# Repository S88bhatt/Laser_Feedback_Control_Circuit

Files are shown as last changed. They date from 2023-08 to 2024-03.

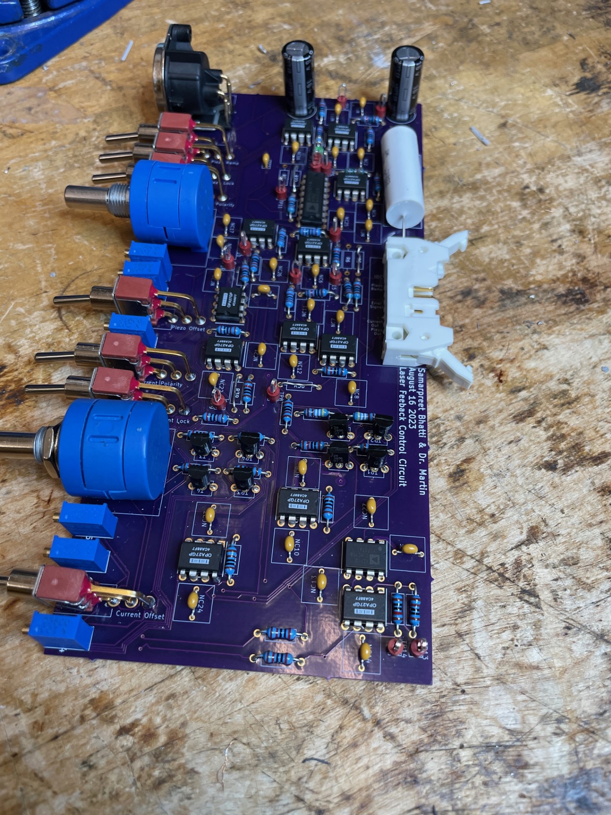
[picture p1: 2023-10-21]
Images/thumbnail_IMG_0441.jpg

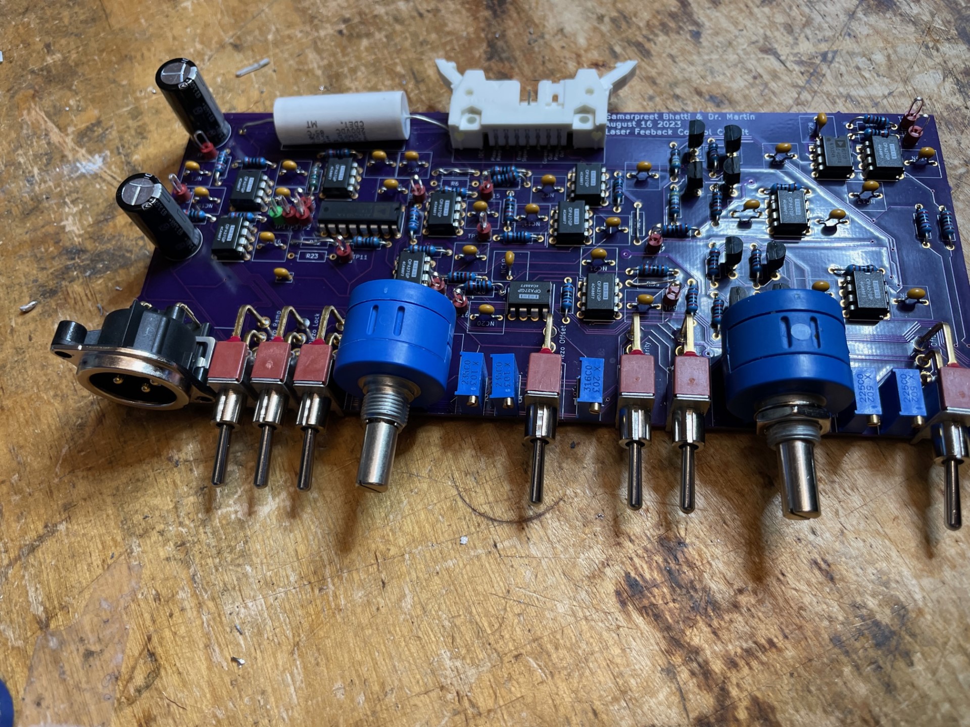
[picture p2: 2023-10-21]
Images/thumbnail_IMG_0439.jpg

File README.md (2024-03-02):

# Laser Feedback Control Circuit
Contains all files in separate folders for the laser feedback control circuit.

## KiCAD
KiCAD Files that are up to date with the most recent and correct version of the circuit, including the PCB layout, schematic, and libraries for footprints and schematic components.

## Gimp
GIMP files which are used for laser cutting the box plating, allowing for a cleaner finish on the final product.

## FreeCAD
FreeCAD files are currently used to cut the box plating into the correct shape.

## Images
Images that show what the physical board looks like once complete.

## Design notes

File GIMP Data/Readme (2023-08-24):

Contains the information to laser cut the lettering onto the box plating

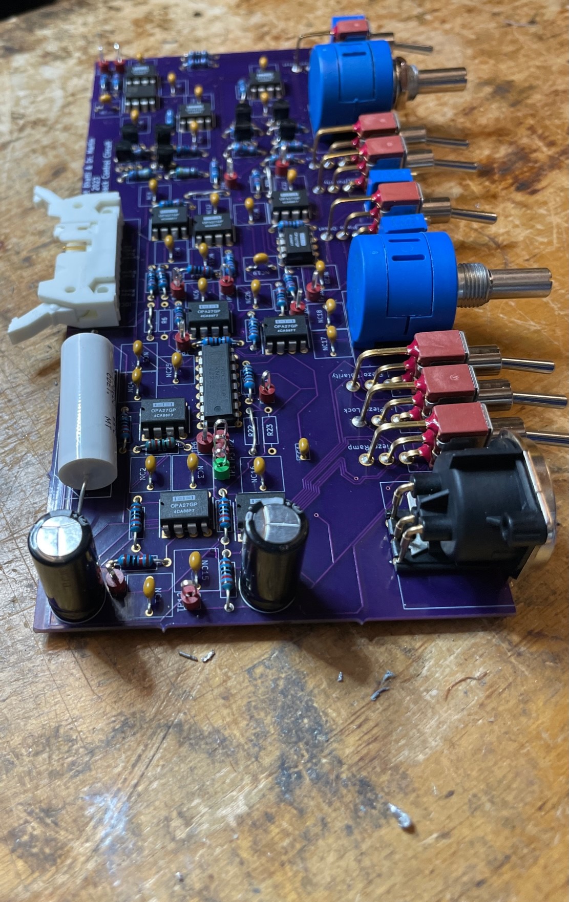
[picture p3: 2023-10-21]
Images/thumbnail_IMG_0442.jpg

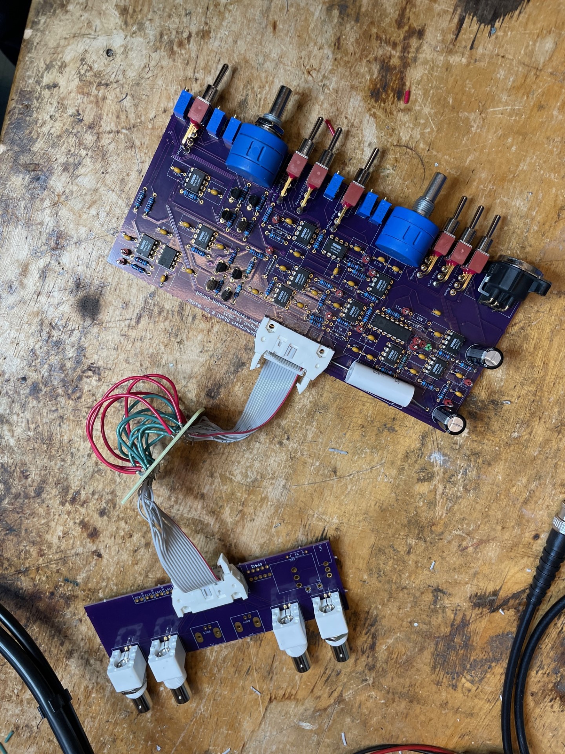
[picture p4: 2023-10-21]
Images/thumbnail_IMG_0443.jpg

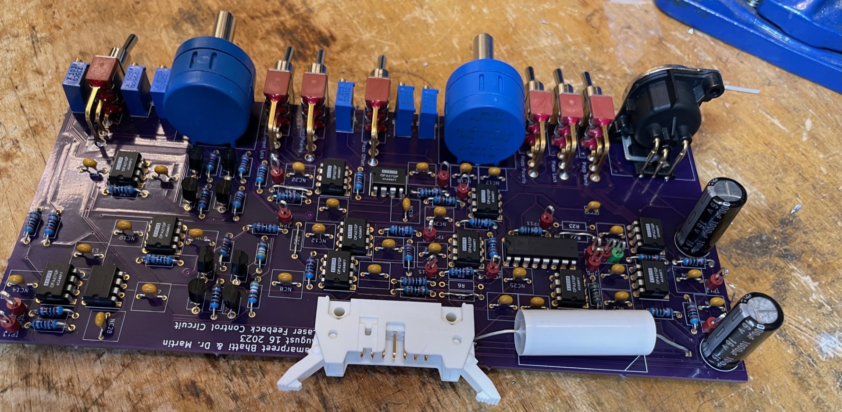
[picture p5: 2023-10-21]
Images/thumbnail_IMG_0440.jpg

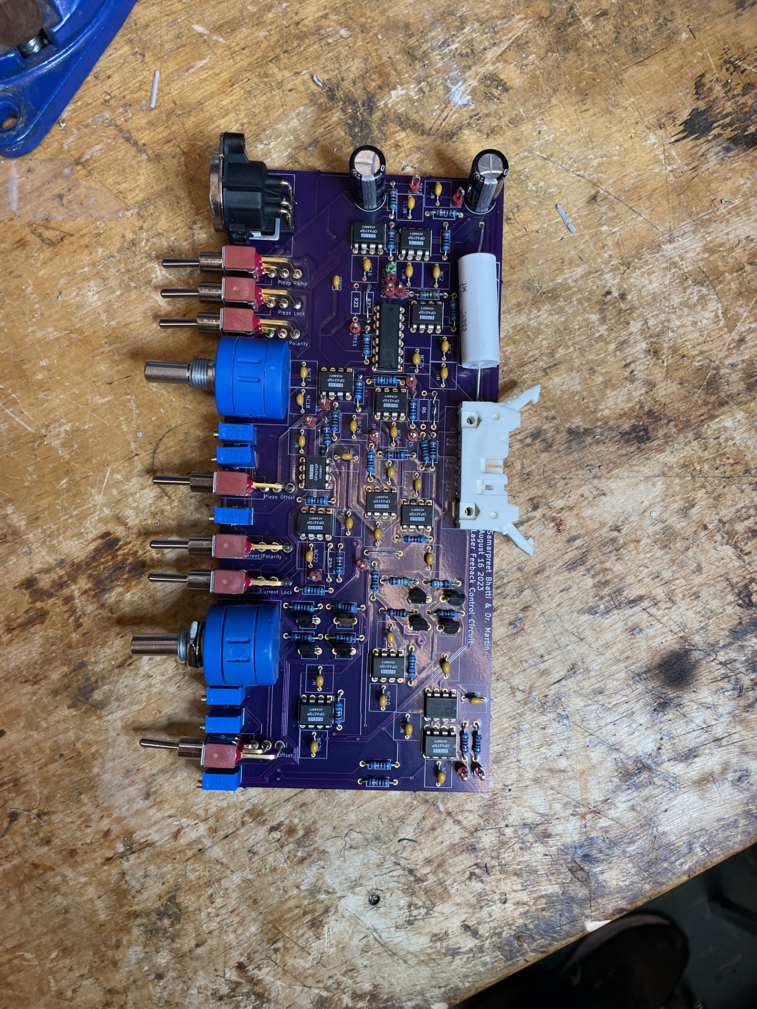
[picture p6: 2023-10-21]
Images/thumbnail_IMG_0438.jpg

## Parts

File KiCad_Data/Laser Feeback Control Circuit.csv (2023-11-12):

Source: | C:\Users\samar\OneDrive\Desktop\SAMARPREET\KiCad\7.0\projects\Laser Feeback Control Circuit\Laser Feeback Control Circuit.kicad_sch
Date: | 2023-10-27 6:58:08 PM
Tool: | Eeschema 7.0.7
Generator: | C:\Program Files\KiCad\7.0\bin\scripting\plugins/bom_csv_grouped_by_value_with_fp.py
Component Count: | 103
Ref | Qnty | Value | Cmp name | Footprint | Description | Vendor | DNP
C1 | 1 | 1uF | Ploypropylene Capacitor | Complex_Op_Amps_Footprints:Polypropylene Capacitor
DG1 | 1 | P/N: ADG201AKNZ | DG201HSDY-T1-E3 | Complex_Op_Amps_Footprints:ADG201AKNZ | Analog Switch ICs HIGH SPEED QUAD SPST A/S
EC1, EC2 | 2 | 1000uF | EEU-EB1C102 | Complex_Op_Amps_Footprints:ELECTROLYTIC CAPACITOR - EEU-EB1C102 | PANASONIC - EEU-EB1C102 - ALUMINUM ELECTROLYTIC CAPACITOR, 1000UF, 20%, 16V, RADIAL
IDC1 | 1 | Male 14 Position IDC Connector, Digikey P/N: 609-5970-ND | 14_Position_Male_IDC | Complex_Op_Amps_Footprints:Male IDC Connector
NC1, NC2, NC6, NC7, NC11, NC14, NC19, NC23, NC25, NC26, NC27, NC28 | 12 | 0.1uF | Normal_Capacitor_399-4209-ND | Complex_Op_Amps_Footprints:CAPACITOR - 399-4209-ND
OP47GP1, OP47GP2, OP47GP3 | 3 | ~ | Quad_Op-Amp_3 | Complex_Op_Amps_Footprints:OP470GPZ
P1, P2 | 2 | 50k | Potentiometer_1 | Complex_Op_Amps_Footprints:Potentiometer
R1, R2, R3, R4, R8, R9, R10, R11, R12, R14, R16, R19, R20, R21, R26, R28, R29, R33, R34, R36, R37 | 21 | 10k | Resistor | Complex_Op_Amps_Footprints:R_Axial_DIN0207_L6.3mm_D2.5mm_P10.16mm_Horizontal
R5, R22, R38, R39 | 4 | 0k | Resistor | Complex_Op_Amps_Footprints:R_Axial_DIN0207_L6.3mm_D2.5mm_P10.16mm_Horizontal
R6, R23 | 2 | Open | Resistor | Complex_Op_Amps_Footprints:R_Axial_DIN0207_L6.3mm_D2.5mm_P10.16mm_Horizontal
R7, R13, R15, R24, R25, R27, R35 | 7 | 1k | Resistor | Complex_Op_Amps_Footprints:R_Axial_DIN0207_L6.3mm_D2.5mm_P10.16mm_Horizontal
R17, R18 | 2 | 5k | Resistor | Complex_Op_Amps_Footprints:R_Axial_DIN0207_L6.3mm_D2.5mm_P10.16mm_Horizontal
R30, R31, R32, R40, R41 | 5 | 20k | Resistor | Complex_Op_Amps_Footprints:R_Axial_DIN0207_L6.3mm_D2.5mm_P10.16mm_Horizontal
REF1 | 1 | REF02 P/N: REF02CPZ | REF02 | Complex_Op_Amps_Footprints:REF02CPZ
SC1 | 1 | 1nF | Small_Capacitor | Complex_Op_Amps_Footprints:Small Capacitor
SW1, SW2, SW3, SW4, SW5, SW6, SW7 | 7 | SPDT Switch, P/N: 7101SD9AV2BE | Switch | Complex_Op_Amps_Footprints:AV2_Switch
T1, T2, T3, T4 | 4 | Transistor P/N: 2N3906 | Transistor | Complex_Op_Amps_Footprints:Both_Transisitor
TP1, TP2, TP3, TP4, TP5, TP6, TP7, TP8, TP9, TP10, TP11, TP12, TP13, TP14, TP15, TP16 | 16 | TestPoint | TestPoint | GENERAL PROJECT - NUMBER 1 LIBRARY - FOOTPRINTS:TestPoint | test point
TR1, TR2, TR3, TR4 | 4 | Transistor P/N: 2N3904 | Transistor2 | Complex_Op_Amps_Footprints:Both_Transisitor
TrimP1 | 1 | 20k | Trim_Potentiometer | Complex_Op_Amps_Footprints:3296X1104LF -TrimPot
TrimP2, TrimP3, TrimP4 | 3 | 10k | Trim_Potentiometer | Complex_Op_Amps_Footprints:3296X1104LF -TrimPot
TrimP5, TrimP6 | 2 | 5k | Trim_Potentiometer | Complex_Op_Amps_Footprints:3296X1104LF -TrimPot
XLR1 | 1 | XLR P/N: NC3MBH | XLR | GENERAL PROJECT - NUMBER 1 LIBRARY - FOOTPRINTS:NC3MBH | Conn XLR Connector Adapter M 3 POS Solder RA Thru-Hole 3 Terminal 1 Port

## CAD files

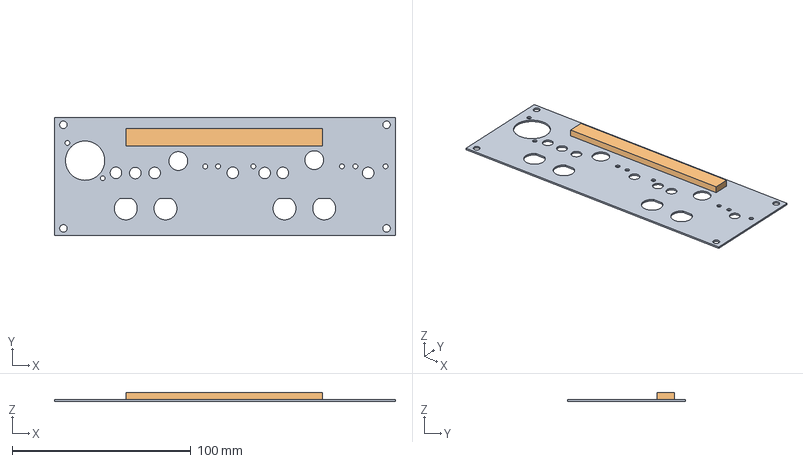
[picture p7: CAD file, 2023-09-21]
FreeCad_Data/Laser_Feedback_Control_Cirucuit_Cut.FCStd
191.0 x 66.0 x 5.00 mm

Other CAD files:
FreeCad_Data/Laser_Feedback_Control_Cirucuit_Cut.stl

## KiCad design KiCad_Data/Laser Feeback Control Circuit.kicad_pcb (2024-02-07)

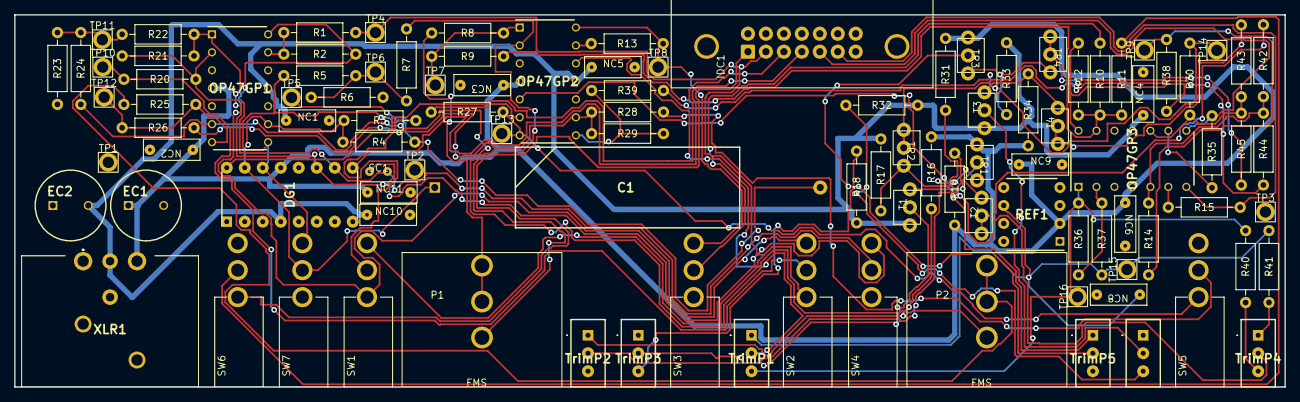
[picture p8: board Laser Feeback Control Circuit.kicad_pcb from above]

Board: 2 copper layers, 179.6 x 52.6 mm, 105 parts (1 on the bottom side), 65 nets.

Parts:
C1: 1uF; Polypropylene Capacitor
DG1: P/N: ADG201AKNZ; ADG201AKNZ
EC1, EC2: 1000uF; ELECTROLYTIC CAPACITOR - EEU-EB1C102
IDC1: Male 14 Position IDC Connector, Digikey P/N: 609-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; Male IDC Connector
NC1, NC2, NC3, NC4, NC5, NC6, NC8, NC9, NC10, NC11: 0.1uF; CAPACITOR - 399-4209-ND
OP47GP1, OP47GP2, OP47GP3: OP470GPZ
P1, P2: 50k; Potentiometer
R1, R2, R3, R4, R8, R9, R10, R11, R12, R14, R17, R19, R20, R21, R26, R28, R29, R33, R34, R36, R37: 10k; R_Axial_DIN0207_L6.3mm_D2.5mm_P10.16mm_Horizontal
R5, R22, R38, R39, R42, R43, R44, R45: 0k; R_Axial_DIN0207_L6.3mm_D2.5mm_P10.16mm_Horizontal
R6, R23: Open; R_Axial_DIN0207_L6.3mm_D2.5mm_P10.16mm_Horizontal
R7, R13, R15, R24, R25, R27, R35: 1k; R_Axial_DIN0207_L6.3mm_D2.5mm_P10.16mm_Horizontal
R16, R18: 5k; R_Axial_DIN0207_L6.3mm_D2.5mm_P10.16mm_Horizontal
R30, R31, R32, R40, R41: 20k; R_Axial_DIN0207_L6.3mm_D2.5mm_P10.16mm_Horizontal
REF1: REF02 P/N: REF02CPZ; REF02CPZ
SC1: 1nF; Small Capacitor
SW1, SW2, SW3, SW4, SW5, SW6, SW7: SPDT Switch, P/N: 7101SD9AV2BE; AV2_Switch
T1, T2, T3, T4: Transistor P/N: 2N3906; Both_Transisitor
TP1, TP2, TP3, TP4, TP5, TP6, TP7, TP8, TP9, TP10, TP11, TP12, TP13, TP14, TP15, TP16: TestPoint
TR1, TR2, TR3, TR4: Transistor P/N: 2N3904; Both_Transisitor
TrimP1: 20k; 3296X1104LF -TrimPot
TrimP2, TrimP3, TrimP4: 10k; 3296X1104LF -TrimPot
TrimP5, TrimP6: 5k; 3296X1104LF -TrimPot
XLR1: XLR P/N: NC3MBH; NC3MBH_XLR

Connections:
+5V: NC8.1 (2), R37.1, R41.2, REF1.6 (VOUT), TP15.1, TrimP1.1
+15V: DG1.13 (V+), EC1.1, NC2.1 (2), NC3.1 (2), NC6.1 (2), NC9.1 (2), NC11.1 (2), OP47GP1.4 (+V), OP47GP2.4 (+V), OP47GP3.4 (+V), R16.1, R19.1, R31.1, R34.1, REF1.2 (VIN), TR1.1 (C), TR3.1 (C), XLR1.2 (+15V)
-5V: OP47GP3.1, R36.2, R40.1, TP16.1, TrimP1.3
-15V: DG1.4 (V-), EC2.2, NC1.1 (2), NC4.1 (2), NC5.1 (2), NC10.1 (2), OP47GP1.11 (V-), OP47GP2.11 (V-), OP47GP3.11 (V-), R17.1, R18.2, R32.2, R33.1, T1.1 (C), T3.1 (C), XLR1.3 (-15V)
GND: DG1.5 (GND), EC1.2, EC2.1, IDC1.7 (C), IDC1.8 (G), IDC1.9 (G), IDC1.10 (G), IDC1.11 (G), IDC1.12 (G), IDC1.13 (G), IDC1.14 (G), NC1.2 (1), NC2.2 (1), NC3.2 (1), NC4.2 (1), NC5.2 (1), NC6.2 (1), NC8.2 (1), NC9.2 (1), NC10.2 (1), NC11.2 (1), OP47GP1.3 (+), OP47GP1.5 (+), OP47GP1.10 (+), OP47GP1.12 (+), OP47GP2.3 (+), OP47GP2.10 (+), OP47GP3.3 (+), OP47GP3.12 (+), R6.1, R23.2, REF1.4 (GND), SW3.1 (A), SW5.3 (C), SW6.3 (C), TP1.1, TP2.1, TP3.1, TrimP2.3, TrimP3.1, TrimP5.3, TrimP6.1, XLR1.1 (GNDC), XLR1.G1
unnamed: C1.1, DG1.15 (D2), OP47GP1.9 (-), R3.2, R4.1, SW7.2 (B)
unnamed: DG1.16 (IN2), IDC1.3 (C)
unnamed: C1.2, DG1.14 (S2), OP47GP1.8, R4.2, R5.1, SW7.3 (C)
unnamed: DG1.10 (D3), OP47GP1.2 (-), R20.2, R21.1, SC1.1, SW4.2 (B)
unnamed: DG1.9 (IN3), IDC1.4 (C)
unnamed: DG1.11 (S3), OP47GP1.1, R21.2, R22.1, SC1.2, SW4.3 (C)
unnamed: IDC1.5 (C), OP47GP3.8, R35.2
unnamed: IDC1.6 (C), OP47GP3.7, R15.2
unnamed: OP47GP1.7, R25.2, R26.1, TP12.1
unnamed: OP47GP1.6 (-), P2.1, R24.2
unnamed: OP47GP1.13 (-), R1.2, R2.1
unnamed: OP47GP2.1, R8.2, R9.1, TP7.1
unnamed: OP47GP2.8, R29.2, R39.1
unnamed: OP47GP2.2 (-), P1.1, R7.2
unnamed: OP47GP2.5 (+), TrimP4.2
unnamed: OP47GP2.6 (-), R27.1
unnamed: OP47GP2.9 (-), R26.2, R28.1, R29.1
unnamed: OP47GP2.12 (+), TrimP1.2
unnamed: OP47GP2.13 (-), R13.1
unnamed: OP47GP3.14, R12.2, R38.1
unnamed: OP47GP3.2 (-), R36.1, R37.2
unnamed: OP47GP3.5 (+), R14.2, R42.2, R44.2
unnamed: OP47GP3.6 (-), R15.1
unnamed: OP47GP3.10 (+), R30.2, R43.2, R45.2
unnamed: OP47GP3.9 (-), R35.1
unnamed: OP47GP3.13 (-), R9.2, R10.1, R11.2, R12.1
unnamed: P1.2, P1.3, R8.1
unnamed: P2.2, P2.3, R25.1
unnamed: R5.2, R6.2, R7.1, TP6.1
unnamed: R14.1, R38.2, TP9.1
unnamed: R16.2, TrimP2.1
unnamed: R18.1, TrimP3.3
unnamed: R22.2, R23.1, R24.1, TP11.1
unnamed: R30.1, R39.2, TP14.1
unnamed: R31.2, TrimP5.1
unnamed: R32.1, TrimP6.3
unnamed: R40.2, TrimP4.3
unnamed: R41.1, TrimP4.1
unnamed: OP47GP1.14, R2.2, SW1.1 (A), SW2.3 (C)
unnamed: R3.1, SW1.2 (B), TP5.1
unnamed: IDC1.2 (C), R1.1, SW1.3 (C), SW2.1 (A), TP4.1
unnamed: R20.1, SW2.2 (B), TP10.1
unnamed: R10.2, SW3.2 (B)
unnamed: OP47GP2.14, R13.2, SW3.3 (C), TP8.1
unnamed: OP47GP2.7, R27.2, SW5.1 (A), TP13.1
unnamed: R28.2, SW5.2 (B)
unnamed: IDC1.1 (C), SW6.1 (A)
unnamed: R11.1, SW6.2 (B)
unnamed: T1.2 (B), TrimP3.2
unnamed: R19.2, T1.3 (E), T2.3 (E)
unnamed: R42.1, T2.1 (C), T2.2 (B)
unnamed: T3.2 (B), TrimP6.2
unnamed: R34.2, T3.3 (E), T4.3 (E)
unnamed: R43.1, T4.1 (C), T4.2 (B)
unnamed: TR1.2 (B), TrimP2.2
unnamed: R17.2, TR1.3 (E), TR2.3 (E)
unnamed: R44.1, TR2.1 (C), TR2.2 (B)
unnamed: TR3.2 (B), TrimP5.2
unnamed: R33.2, TR3.3 (E), TR4.3 (E)
unnamed: R45.1, TR4.1 (C), TR4.2 (B)

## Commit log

2023-08-06 Create Readme-kicad
2023-08-06 Added KiCad Files
    [Complex Op Amps - Project 2 - Part 2.kicad_pcb, Complex Op Amps - Project 2 - Part 2.kicad_sch]
2023-08-07 Made small corrections regarding ground fill
    [Complex Op Amps - Project 2 - Part 2.kicad_pcb]
2023-08-14 Updated files
    Contain Kicad files which include the required capacitors on each op-amp, and additionally electrolytic capacitors were added
    [Complex Op Amps - Project 2 - Part 2.kicad_sch]
2023-08-14 Not required
    Autosave of the current PCB layout kicad makes these occasionally to constantly save progress
2023-08-16 Updated PCB and Schematic
    The PCB has the same changes as the schematic, the schematic had the DPDT switch made into 2 separate switches and capacitors were added onto the DG201 switch's
    [Complex Op Amps - Project 2 - Part 2.kicad_pcb, Complex Op Amps - Project 2 - Part 2.kicad_sch]
2023-08-16 Fixed minor DRC issue with clearance
    [Complex Op Amps - Project 2 - Part 2.kicad_pcb, Complex Op Amps - Project 2 - Part 2.kicad_sch]
2023-08-16 Fixed minor ground fill issue
    Not a critical issue for review, just wires were adjusted so ground fill is fixed
    [Complex Op Amps - Project 2 - Part 2.kicad_pcb]
2023-08-16 Changed Names
    Naming was updated for the symbols to make more sense (adding values for resistance, what each switch does, etc)
    [Complex Op Amps - Project 2 - Part 2.csv, Complex Op Amps - Project 2 - Part 2.kicad_pcb, Complex Op Amps - Project 2 - Part 2.kicad_sch]
2023-08-17 Fixed Wiring that was close to edge
    This version is our first ordered version
    [Complex Op Amps - Project 2 - Part 2.kicad_pcb, Complex Op Amps - Project 2 - Part 2.kicad_sch]
2023-08-17 Added footprints separately
2023-08-17 Added Cutout
    This cutout uses this box 1455U1601 currently. It is not complete since the trim pots need to be measured before I can adjust the height of them
    [Laser_Feedback_Control_Cirucuit_Cut.FCStd]
2023-09-06 Corrected measurements, and added gcode + .stl file
    [Laser_Feedback_Control_Cirucuit_Cut-Extrude.stl, Laser_Feedback_Control_Cirucuit_Cut.FCStd]
2023-09-07 Updated measurements
    [Laser_Feedback_Control_Cirucuit_Cut-Extrude.stl, Laser_Feedback_Control_Cirucuit_Cut.FCStd]
2023-09-14 Updated dimensions
    [Laser_Feedback_Control_Cirucuit_Cut-Extrude.stl, Laser_Feedback_Control_Cirucuit_Cut.FCStd]
2023-09-15 Finding error
    Increased dimensions of all circles at top by 1mm for diameter to find which is causing a problem, the only exception is the XLR which is what every other position is relative to
    [Laser_Feedback_Control_Cirucuit_Cut-Extrude.stl, Laser_Feedback_Control_Cirucuit_Cut.FCStd]
2023-09-21 Updated measurements
    Adjusted measurements for each individual piece, added a bar in the middle to stop bending
    [Laser_Feedback_Control_Cirucuit_Cut-Extrude.stl, Laser_Feedback_Control_Cirucuit_Cut.FCStd]
2023-09-25 Updated IDC connections
    [Complex Op Amps - Project 2 - Part 2.csv, Complex Op Amps - Project 2 - Part 2.kicad_pcb, Complex Op Amps - Project 2 - Part 2.kicad_sch]
2023-09-29 Updated files
    [Laser_Feedback_Control_Cirucuit_Cut.stl]
2023-09-29 Delete FreeCad_Data/Laser_Feedback_Control_Cirucuit_Cut-Extrude_3DPrint.gcode
    Bad Gcode used, ABS was used instead of PLA when slicing
2023-11-12 .\Laser Feedback Control Circuit Footprints.pretty"
    [Laser Feedback Control Circuit.csv, Laser Feedback Control Circuit.kicad_pcb, Laser Feedback Control Circuit.kicad_sch]
2023-11-12 Most Up To Date Version
    [Laser Feeback Control Circuit.csv, Laser Feeback Control Circuit.kicad_pcb, Laser Feeback Control Circuit.kicad_sch]
2024-02-07 Circuit after correction
    Corrections made included:
    - Using quad op-amps which reduced the space needed for the board, however, this made running traces more complicated.
    - There was an error with how the IDC connector was set up in this, and all the pins had to be adjusted.
    - The circuit that limited the maximum and minimum voltages at the end had a correction added where the previous version had a misconnected trace which caused the whole circuit not to function properly additionally, it was split into 2 separate components which were equivalent but did the opposite action and used to make more sense of the circuit as a whole where each was meant to make the most sense relative to what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
    [Laser Feeback Control Circuit.kicad_pcb, Laser Feeback Control Circuit.kicad_sch]
